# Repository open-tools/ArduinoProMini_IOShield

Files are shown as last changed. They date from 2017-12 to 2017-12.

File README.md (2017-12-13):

# ArduinoProMini_IOShield

Quick prototyping breakout board for Arduino Pro Mini with interface for NRF24L01+ and RFM69H wireless modules and breadboards and/or I²C connectors

## Inspiration
This board is inspired by the Arduino "Nano IO Shields" available for cheap at aliexpress (search for "arduino nano nrf24l01 board", e.g. [here](https://www.aliexpress.com/item/Free-shipping-Nano-328P-IO-wireless-sensor-expansion-board-for-XBEE-and-NRF24L01-Socket-for-arduino/32298692903.html)), which provide breakout pins, a connector for an NRF24L01+ module and an XBee module. 
As I don't have any use for the XBee socket, I simply broke off the header pins and instead taped a [tiny 5x11 pin breadboard](https://www.aliexpress.com/item/7Pcs-Mini-55-Points-Breadboard-Solderless-Prototype-Tie-point-For-Arduino-GM/32670910749.html) to the board. 

These boards are perfect for quick prototyping for the MySensors project for several reasons:
* you have the nrf24l01+ radio module already wired with their own voltage regulators and level shifters
* The board has its own power input and voltage regulators (VCC 5V will be fed to the Nano), so sensors with a high current requirement will get the power directly from the supply and not through the Arduino board.
* Each analog and digital pin has its own VCC+GND pins (usually when working with multiple sensors there is a severe shortage of VCC/GND pins for each sensor)
* The I²C and serial (RX/TX) lines are readily available as 1x4 pin headers (i.e. you don't need to know whether A4 or A5 is SDA or SCL).

The only drawback is that I use Pro Minis for most of my projects, so prototyping with a Nano means you are never testing the actual board in the prototype.

## The Board

This board provides 
* each pin of the Arduino Pro Mini as a pin header with its own VCC and GND 
* pads/connectors for a NRF24L01+ or a RFM69H wireless module (and solder pads for an XC6206 5V->3.3V regulator if required)
* I²C connector (VCC, GND, SCL, SDA)
* space for a tiny 55-pin mini breakout board or alternative three additional I²C breakout connections
* solder pads for its own AMS1117 voltage regulator
* ICSP connector to program the bootloader
* drills for the Arduino large enough to fit PogoPins, too, and
* the board outline and the holes are identical to the Arduino Uno, so Arduino holders can be used.

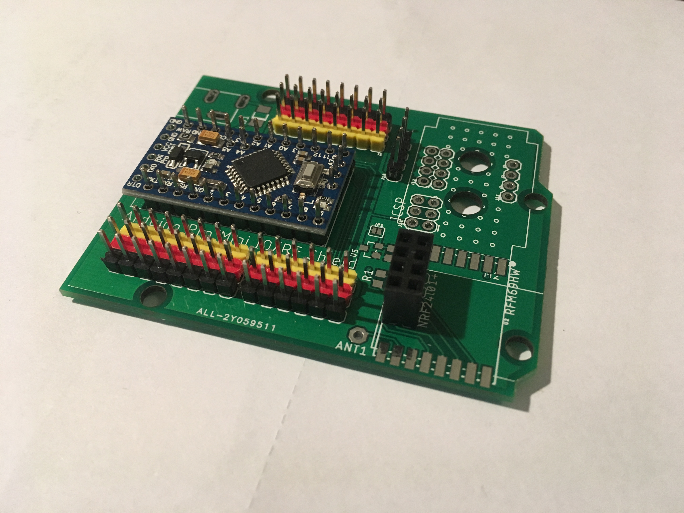
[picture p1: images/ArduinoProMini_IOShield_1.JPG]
Pro Mini IO shield for quick prototyping

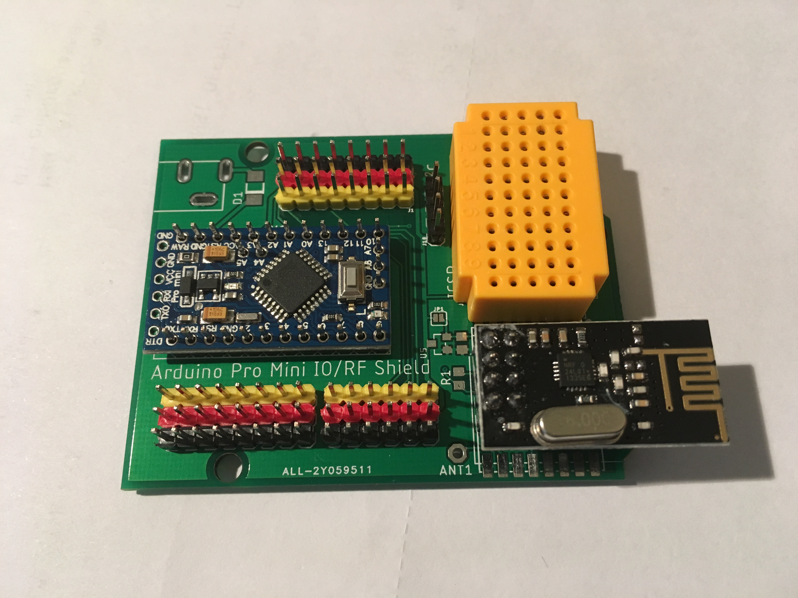
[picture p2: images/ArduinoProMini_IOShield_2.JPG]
Pro Mini IO shield for quick prototyping

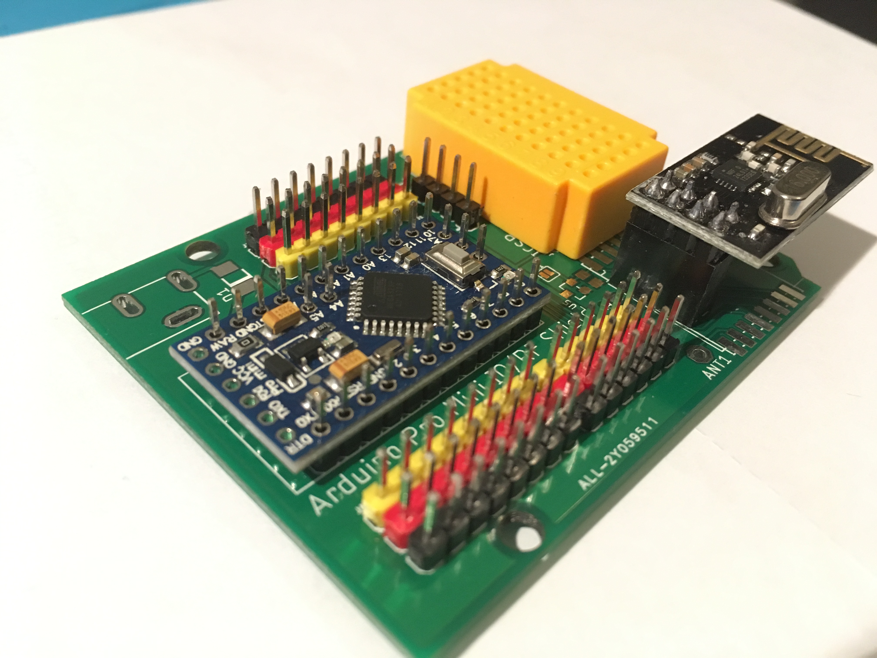
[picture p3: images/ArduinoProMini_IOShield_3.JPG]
Pro Mini IO shield for quick prototyping

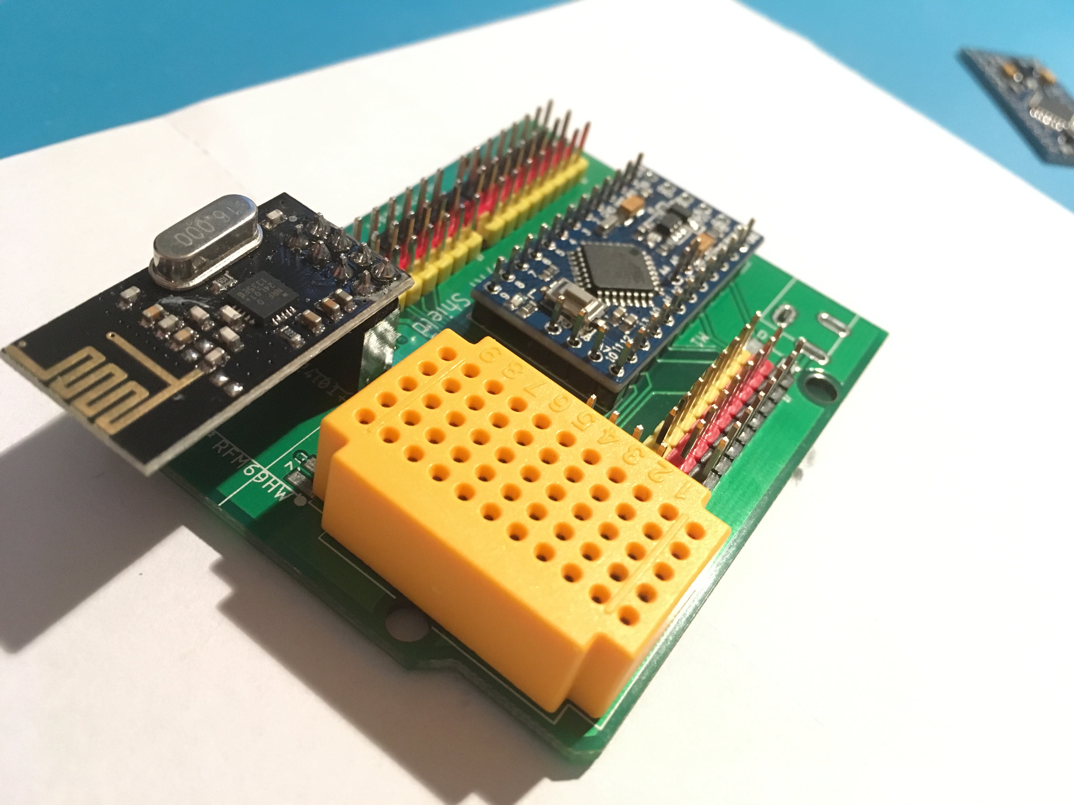
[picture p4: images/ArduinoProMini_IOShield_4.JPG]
Pro Mini IO shield for quick prototyping

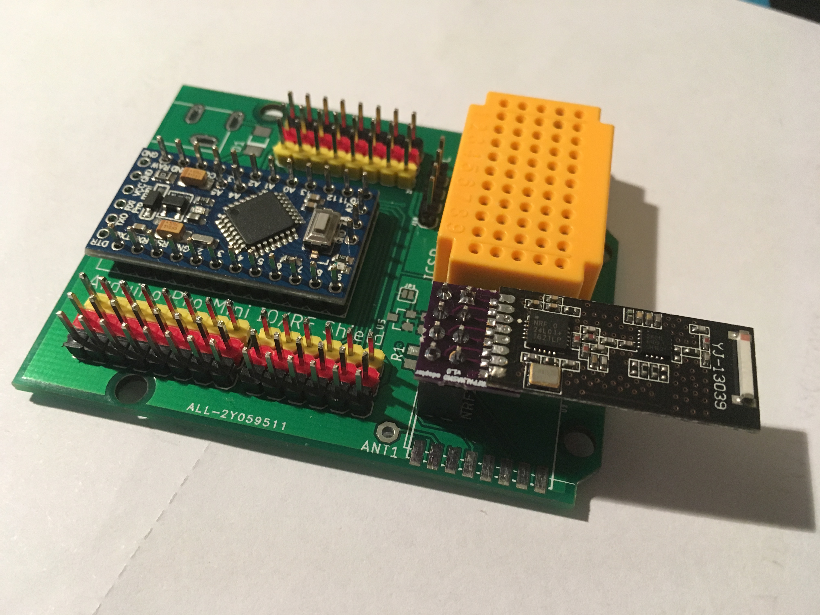
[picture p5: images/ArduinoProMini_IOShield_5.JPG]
SMD nrf24l01+ modules can be used with an adapter

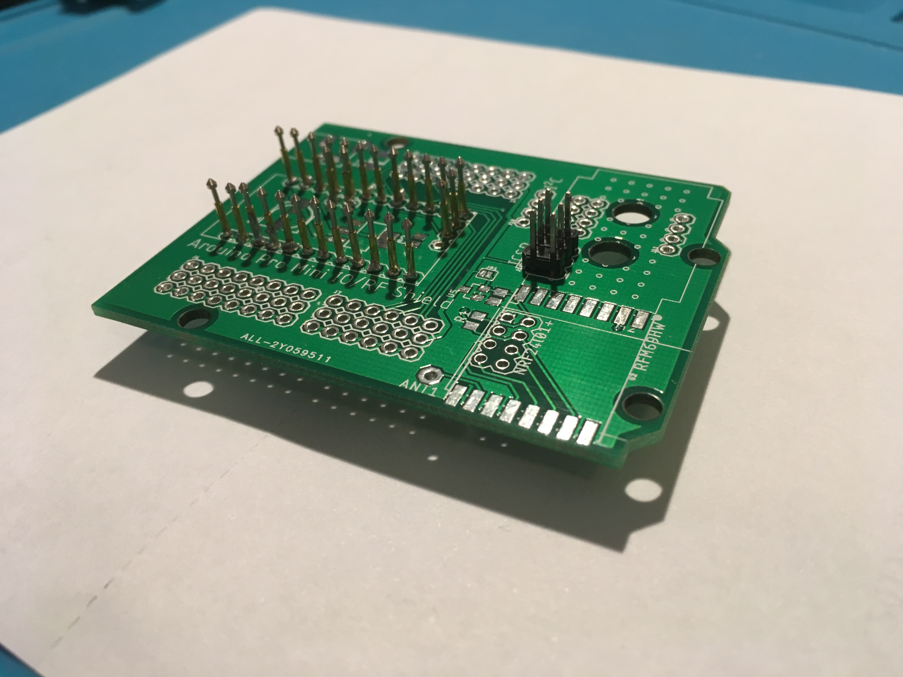
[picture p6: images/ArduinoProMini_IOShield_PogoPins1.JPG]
Pogo pins can be used for ICSP programming Pro Minis

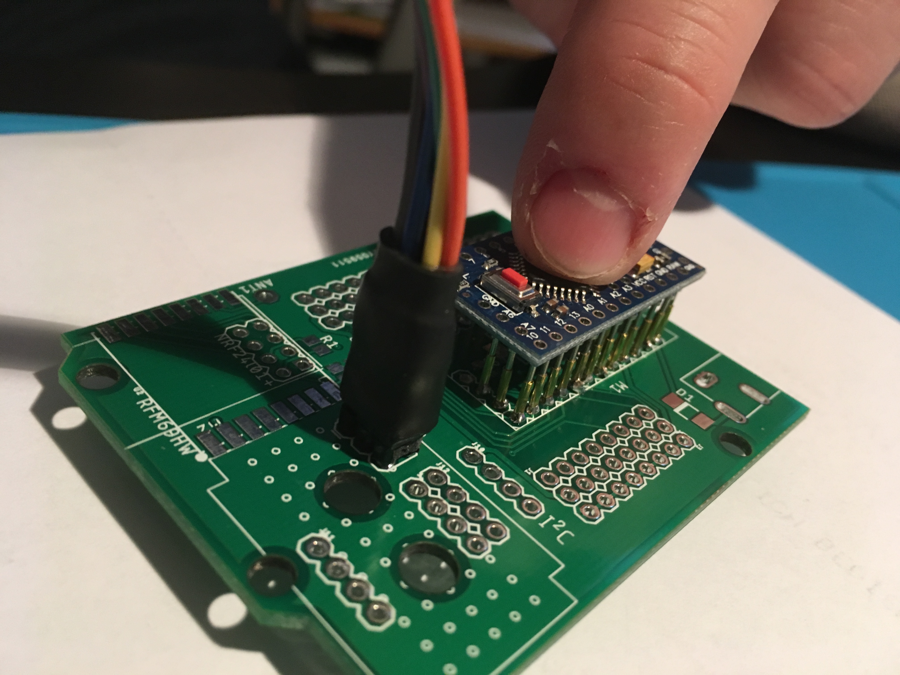
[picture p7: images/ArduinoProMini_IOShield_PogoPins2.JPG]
Pogo pins can be used for ICSP programming Pro Minis

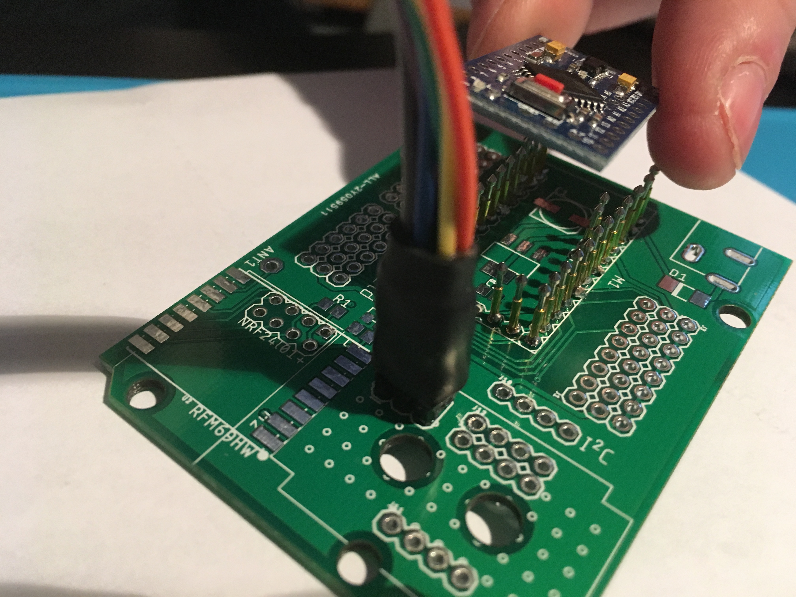
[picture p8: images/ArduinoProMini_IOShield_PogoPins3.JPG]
Pogo pins can be used for ICSP programming Pro Minis

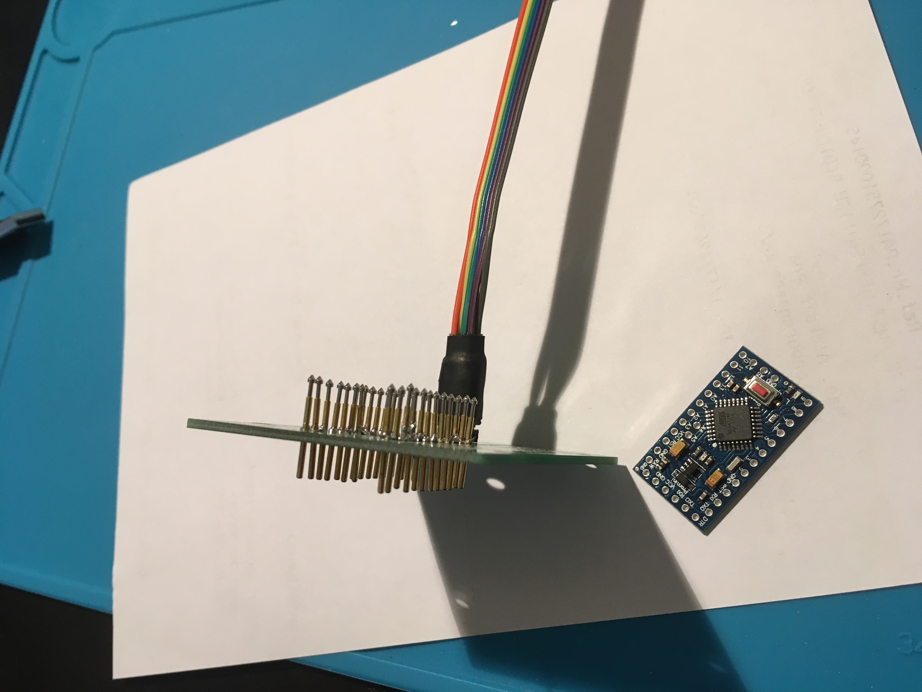
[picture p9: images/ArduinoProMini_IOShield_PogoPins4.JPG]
Pogo pins can be used for ICSP programming Pro Minis


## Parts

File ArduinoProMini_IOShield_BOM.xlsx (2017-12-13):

Qty | Value | Device | Package | Parts | Description | MF | MPN | Aliexpress or Ebay link
1 |  | 5.5x2.1mm Power Jack | POWER_JACK_SLOT | J0 |  |  |  | https://www.aliexpress.com/item/100PCS-LOT-High-Quality-DC-Jack-DC-005-2-0-DC005-Power-Socket-5-5mm-2/32394200270.html
1 | M7 / 1N4007 | SMD diode | DO-214AC | D1 |  |  |  | https://www.aliexpress.com/item/7-kinds-10pcs-70pcs-lot-SMD-diode-package-M1-1N4001-M4-1N4004-M7-1N4007-SS14-US1M/32774058057.html
1 | 100µF | SMD capacitor, | 153CLV-0605 | C1
2 | 10µF | SMD capacitor 0805 | C0805 | C2, C3
1 | AMS1117-5.0 | Voltage Regulator (5V or 3.3V) | SOT223 | U1 | only needed for 5V AMS regulators
 |  | Arduino Pro Mini (or female pin headers) |  | M1
1 | XC6206P332MR-G-SOT23 | XC6206 5V→3.3V regulator (when running with 5V) | SOT-23 | U5
1 | 10k | SMD resistor | R0805 | R1 | Pull-up resistor, exact value not crucial
 | WIRELESS-NRF24L01 | NRF24L01+ SMD wireless module | WIRELESS-NRF24L01 | M2 | optional, either nrf24 or rfm69
 | RFM69HW | RFM69H wireless module | RFM69W-XXXS2 | U2 | optional, either nrf24 or rfm69
 |  | Antenna for RFM69H |  | ANT1 | only for rfm69
 |  | 2.54mm breakable male pin headers |  | J1, J2, J3, J4, J5, J6, J7, J8, J9, J14
 |  | 2.54mm male or female pin headers (optional) | 1X04 | J10, J11, J12, J13
 | Mini 55 Points Breadboard | Tiny 5x11 pin (55 points) Mini Breadboard |  |  |  |  |  | https://www.aliexpress.com/item/7Pcs-Mini-55-Points-Breadboard-Solderless-Prototype-Tie-point-For-Arduino-GM/32670910749.html

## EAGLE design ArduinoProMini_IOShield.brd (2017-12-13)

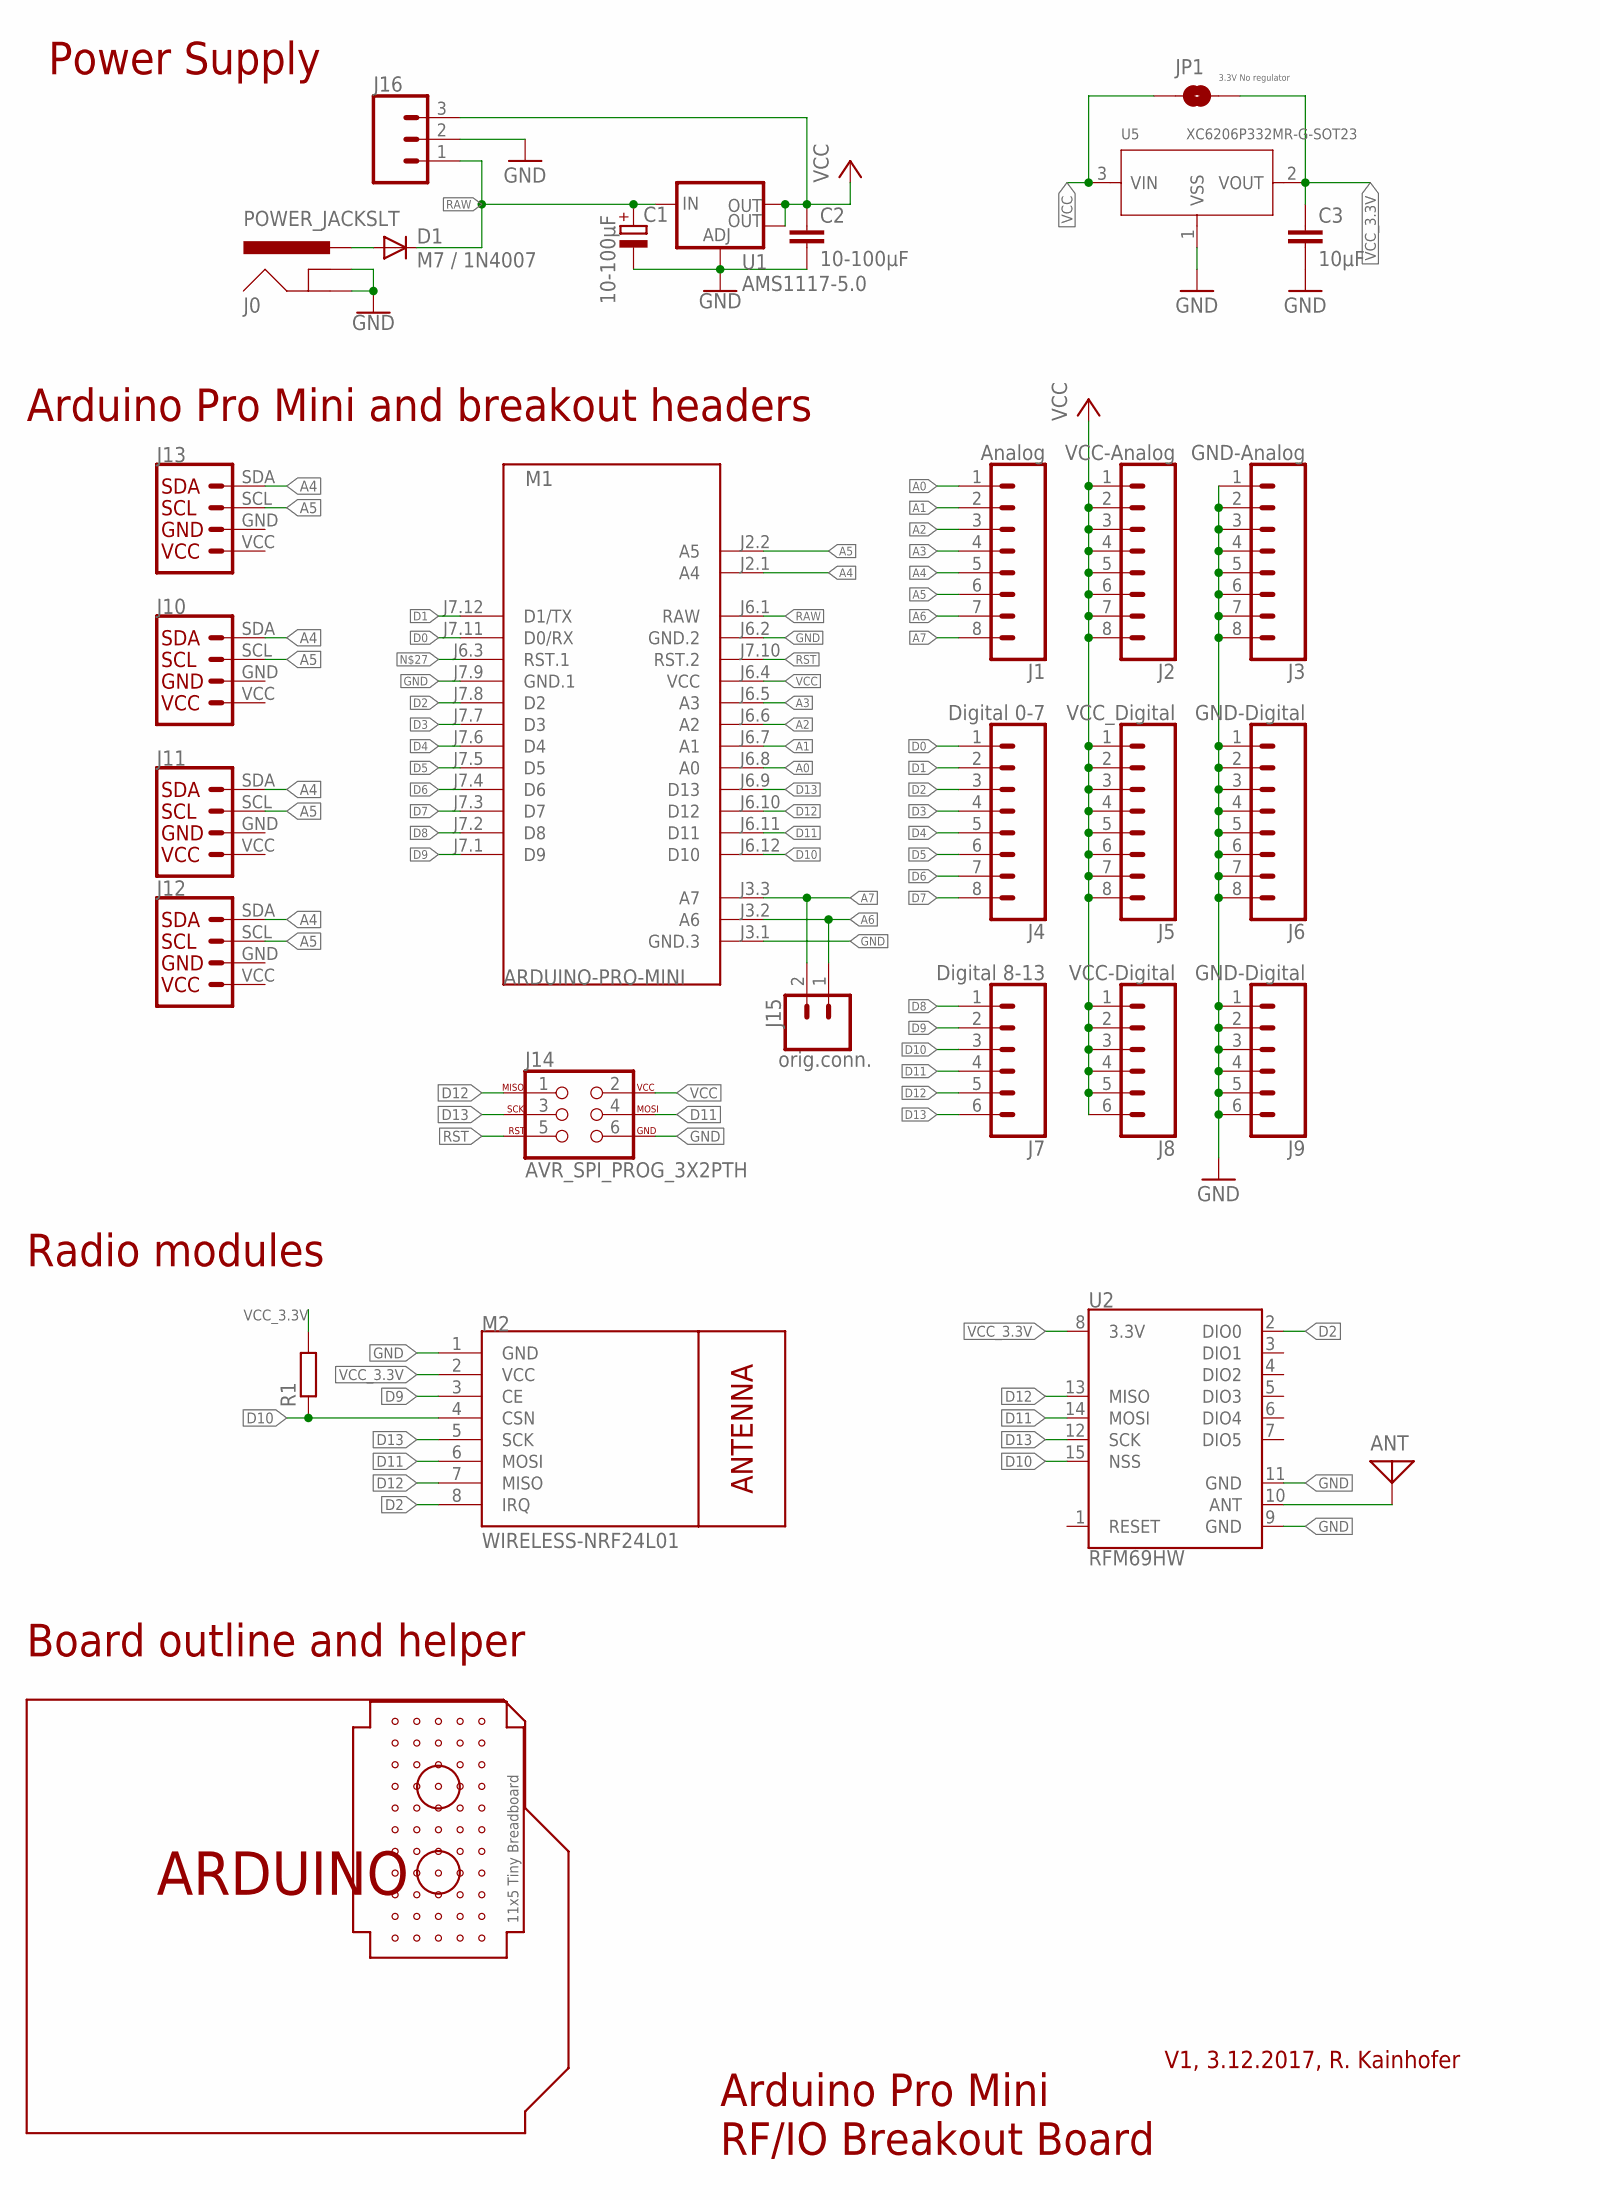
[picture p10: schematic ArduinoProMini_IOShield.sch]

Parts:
ANT: ANTENNA; PAD-01
B1: ARDUINO_DIMENSION-DIMENSION; ARDUINOR3
C1: 10-100µF; 153CLV-0605
C2: 10-100µF; C0805
C3: 10µF; C0805
D1: M7 / 1N4007; DO-214AC
J0: POWER_JACKSLT; POWER_JACK_SLOT
J1: Analog; 1X08
J2: VCC-Analog; 1X08
J3: GND-Analog; 1X08
J4: Digital 0-7; 1X08
J5: VCC_Digital; 1X08
J6: GND-Digital; 1X08
J7: Digital 8-13; 1X06
J8: VCC-Digital; 1X06
J9: GND-Digital; 1X06
J10, J11, J12, J13: I2C_CONN_VGLA; 1X04
J14: AVR_SPI_PROG_3X2PTH; 2X3
J15: orig.conn.; 1X02
J16: CONN_031X03_NO_SILK; 1X03_NO_SILK
JP1: 3.3V No regulator; SMT-JUMPER_2_NO_SILK
M1: ARDUINO-PRO-MINI; ARDUINO-PRO-MINI#NP
M2: WIRELESS-NRF24L01
R1: R-EU_R0805; R0805
U1: AMS1117-5.0; SOT223
U2: RFM69HW; RFM69W-XXXS2
U5: XC6206P332MR-G-SOT23; SOT-23
U$1: MINI_BREADBOARD; MINI_BREADBOARD_11X5

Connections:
A0: J1.1, M1.J6.8 (A0)
A1: J1.2, M1.J6.7 (A1)
A2: J1.3, M1.J6.6 (A2)
A3: J1.4, M1.J6.5 (A3)
A4: J1.5, J10.SDA, J11.SDA, J12.SDA, J13.SDA, M1.J2.1 (A4)
A5: J1.6, J10.SCL, J11.SCL, J12.SCL, J13.SCL, M1.J2.2 (A5)
A6: J1.7, J15.1, M1.J3.2 (A6)
A7: J1.8, J15.2, M1.J3.3 (A7)
D0: J4.1, M1.J7.11 (D0/RX)
D1: J4.2, M1.J7.12 (D1/TX)
D2: J4.3, M1.J7.8 (D2), M2.8 (IRQ), U2.2 (DIO0)
D3: J4.4, M1.J7.7 (D3)
D4: J4.5, M1.J7.6 (D4)
D5: J4.6, M1.J7.5 (D5)
D6: J4.7, M1.J7.4 (D6)
D7: J4.8, M1.J7.3 (D7)
D8: J7.1, M1.J7.2 (D8)
D9: J7.2, M1.J7.1 (D9), M2.3 (CE)
D10: J7.3, M1.J6.12 (D10), M2.4 (CSN), R1.1, U2.15 (NSS)
D11: J7.4, J14.4, M1.J6.11 (D11), M2.6 (MOSI), U2.14 (MOSI)
D12: J7.5, J14.1, M1.J6.10 (D12), M2.7 (MISO), U2.13 (MISO)
D13: J7.6, J14.3, M1.J6.9 (D13), M2.5 (SCK), U2.12 (SCK)
GND: C1.-, C2.2, C3.2, J0.GND@1 (GNDBREAK), J0.GND@2 (GND), J3.1, J3.2, J3.3, J3.4, J3.5, J3.6, J3.7, J3.8, J6.1, J6.2, J6.3, J6.4, J6.5, J6.6, J6.7, J6.8, J9.1, J9.2, J9.3, J9.4, J9.5, J9.6, J10.GND, J11.GND, J12.GND, J13.GND, J14.6, J16.2, M1.J3.1 (GND.3), M1.J6.2 (GND.2), M1.J7.9 (GND.1), M2.1 (GND), U1.1 (ADJ), U2.9 (GND), U2.11 (GND), U5.1 (VSS)
unnamed: D1.A, J0.PWR
unnamed: ANT.1, U2.10 (ANT)
RAW: C1.+, D1.C, J16.1, M1.J6.1 (RAW), U1.3 (IN)
RST: J14.5, M1.J7.10 (RST.2)
VCC: C2.1, J2.1, J2.2, J2.3, J2.4, J2.5, J2.6, J2.7, J2.8, J5.1, J5.2, J5.3, J5.4, J5.5, J5.6, J5.7, J5.8, J8.1, J8.2, J8.3, J8.4, J8.5, J8.6, J10.VCC, J11.VCC, J12.VCC, J13.VCC, J14.2, J16.3, JP1.1, M1.J6.4 (VCC), U1.2 (OUT), U1.4 (OUT), U5.3 (VIN)
VCC_3.3V: C3.1, JP1.2, M2.2 (VCC), R1.2, U2.8 (3.3V), U5.2 (VOUT)

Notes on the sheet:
Power Supply
Arduino Pro Mini and breakout headers
Radio modules
Board outline and helper
Arduino Pro Mini RF/IO Breakout Board
V1, 3.12.2017, R. Kainhofer

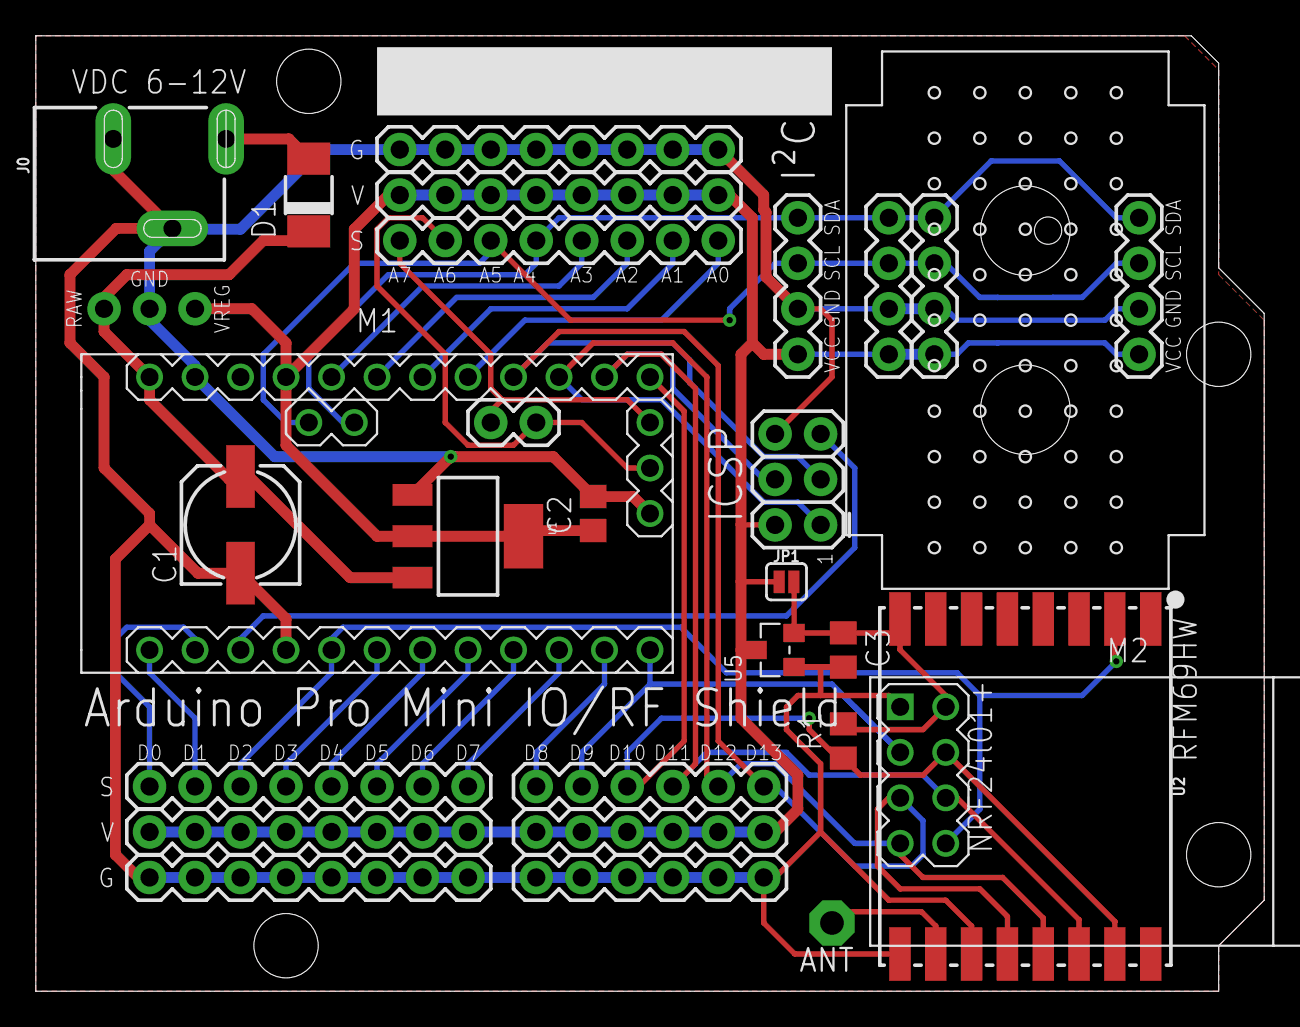
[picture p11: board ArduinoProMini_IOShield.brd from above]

Board: 2 copper layers, 68.6 x 53.3 mm, 31 parts (0 on the bottom side), 29 nets.

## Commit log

2017-12-08 Board design
    [ArduinoProMini_IOShield.GBL, ArduinoProMini_IOShield.GBO, ArduinoProMini_IOShield.GBP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]
2017-12-08 Updated BOM
    [ArduinoProMini_IOShield_BOM.xlsx]
2017-12-09 Update README and BOM
    [ArduinoProMini_IOShield_BOM.xlsx]
2017-12-13 V0.2: Add power soldering connection, add altenative ProMini pinout, move ICSP header; Add pictures;
    [ArduinoProMini_IOShield.brd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]

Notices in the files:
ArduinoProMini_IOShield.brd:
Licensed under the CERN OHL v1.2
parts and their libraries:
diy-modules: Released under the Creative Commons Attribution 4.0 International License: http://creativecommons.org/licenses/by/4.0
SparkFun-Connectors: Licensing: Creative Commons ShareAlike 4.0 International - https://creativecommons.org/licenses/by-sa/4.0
